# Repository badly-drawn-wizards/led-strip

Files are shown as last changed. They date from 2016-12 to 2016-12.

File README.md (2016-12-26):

# Description #
This is a Ethernet controlled RGB led-strip music visualizer. It uses WS2812
strip for display, a PIC16F1825 as a host controller and a ENC28J60 for ethernet
communication. The communication is one-way with raw ethernet frames (Yay! It's terrible). This
project has three parts

- Host controller code in __micro__
- A __daemon__ to listen to a pulseaudio monitor and send the visualization to the led-strip device with a hard-coded MAC address.
- A _completely untested_ __board__ design for the device. I'll return to it someday. Maybe.

# Demo #
[In this YouTube video](https://youtu.be/0CW2xSNjpUU) is a demonstration of a breadboard prototype.

# Disclaimer #
This project is entirely for my own satisfaction and not left in a complete, nor readily consumable state.

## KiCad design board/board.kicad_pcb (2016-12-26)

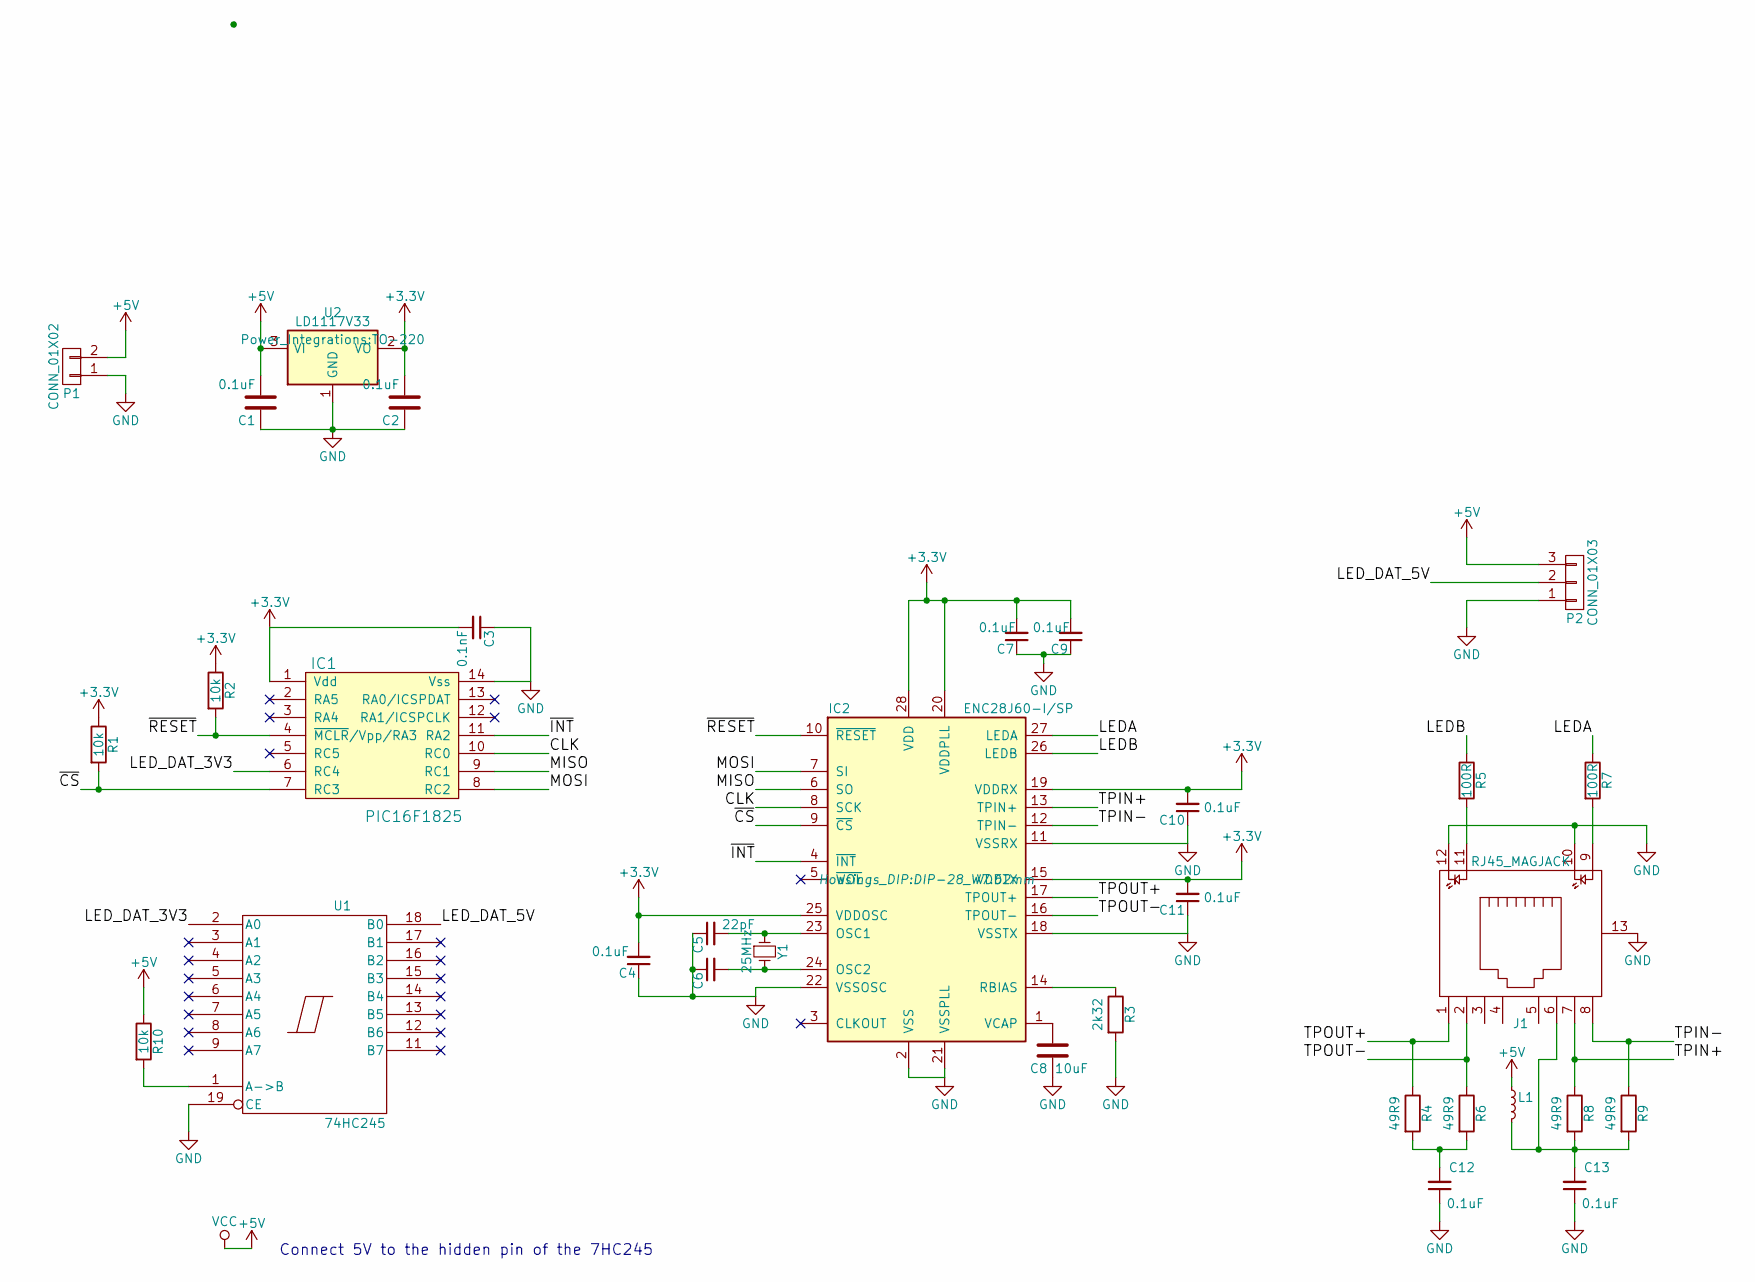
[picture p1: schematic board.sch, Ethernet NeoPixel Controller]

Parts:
C1, C2, C4, C7, C9, C10, C11, C12, C13: 0.1uF; C_Disc_D3_P2.5
C3: 0.1nF; C_Disc_D3_P2.5
C5, C6: 22pF; C_Disc_D3_P2.5
C8: 10uF; C_Radial_D5_L6_P2.5
IC1: PIC16F1825; DIP-14_W7.62mm
IC2: ENC28J60-I/SP; DIP-28_W7.62mm
J1: RJ45_MAGJACK
L1: L_Small; Choke_Horizontal_RM10mm
P1: CONN_01X02; Pin_Header_Straight_1x02
P2: CONN_01X03; Pin_Header_Straight_1x03
R1, R2, R10: 10k; Resistor_Horizontal_RM10mm
R3: 2k32; Resistor_Horizontal_RM10mm
R4, R6, R8, R9: 49R9; Resistor_Horizontal_RM10mm
R5, R7: 100R; Resistor_Horizontal_RM10mm
U1: 74HC245; DIP-20_W7.62mm
U2: LD1117V33; TO-220
Y1: 25MHz; Crystal_HC49-U_Vertical

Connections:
+3V3: C2.2, C3.2, C4.2, C7.2, C9.2, C10.2, C11.2, IC1.1 (Vdd), IC2.15 (VDDTX), IC2.19 (VDDRX), IC2.20 (VDDPLL), IC2.25 (VDDOSC), IC2.28 (VDD), R1.1, R2.1, U2.2 (VO)
+5V: C1.2, L1.1, P1.2, P2.3, R10.1, U1.20 (VCC), U2.3 (VI)
/CLK: IC1.10 (RC0), IC2.8 (SCK)
/LEDA: IC2.27 (LEDA), R7.1
/LEDB: IC2.26 (LEDB), R5.1
/LED_DAT_3V3: IC1.6 (RC4), U1.2 (A0)
/LED_DAT_5V: P2.2, U1.18 (B0)
/MISO: IC1.9 (RC1), IC2.6 (SO)
/MOSI: IC1.8 (RC2), IC2.7 (SI)
/TPIN+: IC2.13 (TPIN+), J1.7, R8.1
/TPIN-: IC2.12 (TPIN-), J1.8, R9.1
/TPOUT+: IC2.17 (TPOUT+), J1.1, R4.1
/TPOUT-: IC2.16 (TPOUT-), J1.2, R6.1
/~CS~: IC1.7 (RC3), IC2.9 (~CS), R1.2
/~INT~: IC1.11 (RA2), IC2.4 (~INT)
/~RESET~: IC1.4 (~MCLR~/Vpp/RA3), IC2.10 (~RESET), R2.2
GND: C1.1, C2.1, C3.1, C4.1, C5.1, C6.1, C7.1, C8.1, C9.1, C10.1, C11.1, C12.1, C13.1, IC1.14 (Vss), IC2.2 (VSS), IC2.11 (VSSRX), IC2.18 (VSSTX), IC2.21 (VSSPLL), IC2.22 (VSSOSC), J1.10, J1.12, J1.13, P1.1, P2.1, R3.2, U1.10 (GND), U1.19 (CE), U2.1 (GND)
unnamed: C5.2, IC2.23 (OSC1), Y1.1
unnamed: C6.2, IC2.24 (OSC2), Y1.2
unnamed: C8.2, IC2.1 (VCAP)
unnamed: C12.2, R4.2, R6.2
unnamed: C13.2, J1.6, L1.2, R8.2, R9.2
unnamed: IC2.14 (RBIAS), R3.1
unnamed: J1.9, R7.2
unnamed: J1.11, R5.2
unnamed: R10.2, U1.1 (A->B)

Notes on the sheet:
Connect 5V to the hidden pin of the 7HC245

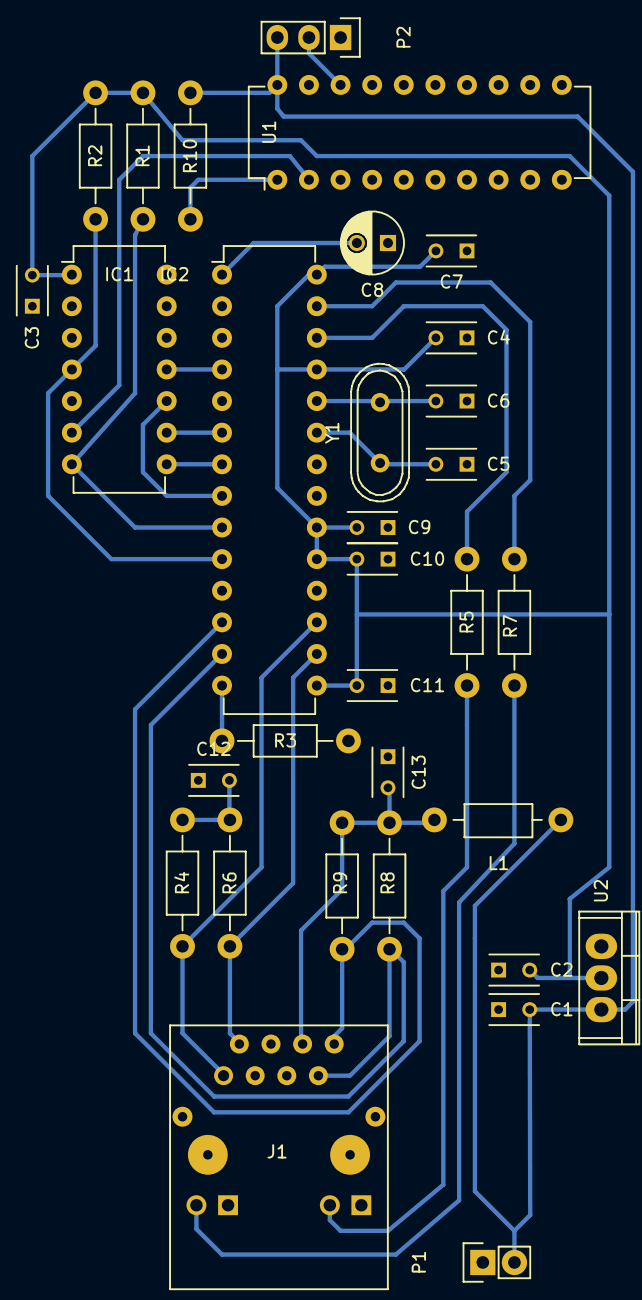
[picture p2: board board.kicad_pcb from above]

Board: 2 copper layers, 32 parts (0 on the bottom side), 26 nets.

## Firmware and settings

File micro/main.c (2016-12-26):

#include <xc.h>
#include <stdint.h>
#include <stdio.h>
#include <spi.h>
#include <enc28j60.h>
#include <lg_arr.h>
#include <timing.h>
#include <ws2812.h>

#pragma config WDTE = OFF

#define LEDS 120
#define LED(REG) REG##Cbits.REG##C4

inline uint8_t uabs(uint8_t x, uint8_t offset) {
  return x < offset ? offset-x : x-offset;
}

inline uint8_t triangle(uint16_t height, uint16_t half_period, uint16_t x) {
  return uabs(x%(2*half_period),half_period) * height / half_period;
}

LG_ARR_DECL(colors, 3*LEDS, 3)

void init_leds() {
  LED(TRIS) = 0;
  LED(LAT) = 0;
}

void send_leds() {
  uint8_t val;
  LG_ARR_SEND_COLOR_HELPER(LED(LAT), colors, 0);
  LG_ARR_SEND_COLOR_HELPER(LED(LAT), colors, 1);
  LG_ARR_SEND_COLOR_HELPER(LED(LAT), colors, 2);
  LG_ARR_SEND_COLOR_HELPER(LED(LAT), colors, 3);
  LG_ARR_SEND_COLOR_HELPER(LED(LAT), colors, 4);
  latch_color();
}

uint8_t MAC_ADDR[6] = {0x00, 0x01, 0x02, 0x03, 0x04, 0x05};

void init_ethernet() {
  // Set rx buffer limits
  enc_wcr(ENC_ERXSTH, 0x00);
  enc_wcr(ENC_ERXSTL, 0x00);
  enc_wcr(ENC_ERXNDH, 0x1F);
  enc_wcr(ENC_ERXNDL, 0xFF);

  enc_rcr(ENC_ERXSTL);
  enc_rcr(ENC_ERXSTH);
  enc_rcr(ENC_ERXNDL);
  enc_rcr(ENC_ERXNDH);

  // Receive only unicast packets
  enc_wcr(ENC_ERXFCON, ENC_ERXFCON_UCEN);

  // Enable interrupts when a packet is received
  enc_bfs(ENC_EIE, ENC_EIE_PKIE | ENC_EIE_INTIE);
  // Set interrupt pin edge _before_ enabling pin,
  // otherwise the interrupt flag is erronously set.
  OPTION_REGbits.INTEDG = 0;
  ANSELAbits.ANSA2 = 0;
  TRISAbits.TRISA2 = 1;
  INTCONbits.INTE = 1;

  // Poll the oscillator start-up timer
  while(!(enc_rcr(ENC_ESTAT) & ENC_ESTAT_CLKRDY));

  // Enable the MAC reception of frames
  enc_bfs(ENC_MACON1, ENC_MACON1_MARXEN);
  // Enable frame length checking
  enc_bfs(ENC_MACON3, ENC_MACON3_FRMLNEN);
  // Half-duplex mode
  enc_bfc(ENC_MACON3, ENC_MACON3_FULDPX);

  // Set max frame length (1518 bytes)
  enc_wcr(ENC_MAMXFLL, 0xEE);
  enc_wcr(ENC_MAMXFLH, 0x05);

  // (Probably not required) Set non-back-to-back inter-packet gap
  enc_wcr(ENC_MAIPGL, 0x12);
  enc_wcr(ENC_MAIPGH, 0x0C);

  // Set MAADR registers
  enc_wcr(ENC_MAADR1, MAC_ADDR[0]);
  enc_wcr(ENC_MAADR2, MAC_ADDR[1]);
  enc_wcr(ENC_MAADR3, MAC_ADDR[2]);
  enc_wcr(ENC_MAADR4, MAC_ADDR[3]);
  enc_wcr(ENC_MAADR5, MAC_ADDR[4]);
  enc_wcr(ENC_MAADR6, MAC_ADDR[5]);

  // Enable reception of frames
  enc_bfs(ENC_ECON1, ENC_ECON1_RXEN);
}

#define STATUS_AND_HEADER_LENGTH (2 + 4 + 6 + 6 + 2)

uint8_t dropped_packets = 0;
uint8_t handled_packets = 0;

uint16_t last_packet = 0;
void process_packets() {
  uint8_t pktcnt;
  // Process all packets
  while((pktcnt = enc_rcr(ENC_EPKTCNT)) > 0) {

    // Might have to add logic to disable RX if
    // there are too many dropped packets

    // Set read pointer
    enc_wcr(ENC_ERDPTL, last_packet);
    enc_wcr(ENC_ERDPTH, last_packet >> 8);

    // Read the next packet pointer, the receive status vector and the packet header
    uint8_t status_and_header[STATUS_AND_HEADER_LENGTH];
    enc_rbm(status_and_header, STATUS_AND_HEADER_LENGTH);

    // Extract the next packet pointer
    last_packet = *((uint16_t *)status_and_header);

    // Extract the length
    uint16_t length = ((uint16_t)status_and_header[18] << 8) + status_and_header[19];

    // Only copy the latest packet
    if(pktcnt == 1) {
      // Copy packet payload
      LG_ARR_PART(colors, colors_part, colors_part_size, {
            enc_rbm(colors_part, length < colors_part_size ? length : colors_part_size);
          length = colors_part_size > length ? 0 : length - colors_part_size;
        });
    } else {
      ++dropped_packets;
    }

    // Free buffer space
    // an odd address must be written due to Errata B7.11
    enc_wcr(ENC_ERXRDPTL, (last_packet - 1));
    enc_wcr(ENC_ERXRDPTH, (last_packet - 1) >> 8);

    // Decrement packet counter
    enc_bfs(ENC_ECON2, ENC_ECON2_PKTDEC);

    ++handled_packets;

    if(pktcnt == 1) break;
  }
}

volatile uint8_t receiving_colors;
void receive_colors() {
  receiving_colors = 1;
  INTCONbits.GIE = 1;
  while(receiving_colors) {}
  INTCONbits.GIE = 0;
}


int main() {
  // 16 Mhz clock
  OSCCONbits.SCS = 0b10;
  OSCCONbits.IRCF = 0b1111;

  __delay_ms(100);

  init_leds();
  init_spi();
  init_ethernet();

  while (1) {
    receive_colors();
    send_leds();
  }
}

void interrupt ISR() {
  if(INTCONbits.INTF) {
    process_packets();
    receiving_colors = 0;
    INTCONbits.INTF = 0;
  }
}

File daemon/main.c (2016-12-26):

#include <time.h>
#include <pulse.h>
#include <backends/sdl_backend.h>
#include <backends/led_strip_backend.h>
#include <visualizers/volume_visualizer.h>
#include <visualizers/test_visualizer.h>

#define BUF_SIZE 512
#define NUM_LEDS 120
#define PERIOD 100000

int main() {
  led_backend led_strip_backend;
  led_backend sdl_backend;
  get_led_strip_backend(&led_strip_backend);
  get_sdl_backend(&sdl_backend);
  led_visualizer visualizer = volume_visualizer;

  color led_colors[NUM_LEDS];
  pulse_context *pulse = pulse_context_new(BUF_SIZE);
  void *led_strip_backend_context = led_strip_backend.backend_init();
  void *sdl_backend_context = sdl_backend.backend_init();
  uint16_t cnt = 0;
  struct timeval now;
  while(1) {
    gettimeofday(&now, NULL);
    suseconds_t usec = now.tv_usec;
    double time = now.tv_sec + now.tv_usec / 1E6;
    pulse_get_sample(pulse);
    visualizer(time, pulse->buf, pulse->buf_size, led_colors, NUM_LEDS);
    led_strip_backend.send_leds(led_colors, NUM_LEDS, led_strip_backend_context);
    sdl_backend.send_leds(led_colors, NUM_LEDS, sdl_backend_context);

    gettimeofday(&now, NULL);
    uint32_t elapsed = now.tv_usec - usec;
    usleep(elapsed<PERIOD ? PERIOD-elapsed : 0);
    ++cnt;
  }
  led_strip_backend.backend_free(led_strip_backend_context);
  sdl_backend.backend_free(sdl_backend_context);
  pulse_context_free(pulse);
}

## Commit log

2016-09-29 Version .dir-locals.el
2016-09-30 Fixed SPI by clearing ANSELC on all SPI pins.
2016-10-01 Initial schematic design
    [board.kicad_pcb, board.sch]
2016-10-03 Finished PCB
    [board.kicad_pcb, board.sch]
2016-10-03 Initial work to send raw ethernet frames.
2016-10-03 Add .dir-locals.el for daemon.
2016-10-03 Set LED_PIN correctly
2016-10-03 Extract function for led initialization
2016-10-03 Group interrupt related code together
2016-10-03 Fixed incorrect offset to packet length.
    [main.c]
2016-10-03 Fix potential buffer over-read
    [main.c]
2016-12-26 Rest of the owl (board edition)
    [board.kicad_pcb]
